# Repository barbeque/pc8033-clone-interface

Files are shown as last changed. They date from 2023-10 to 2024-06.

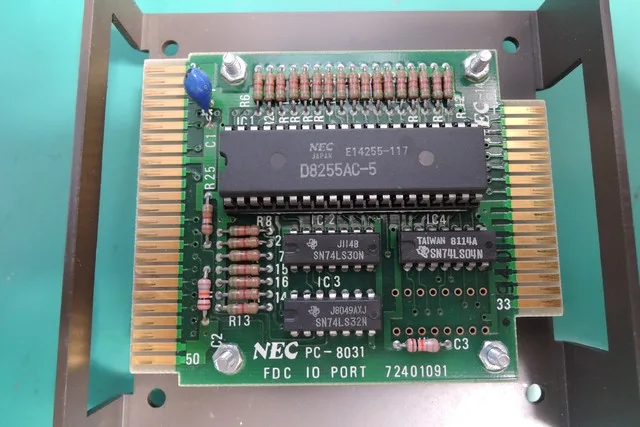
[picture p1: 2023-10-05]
References/real-pc-8033.webp

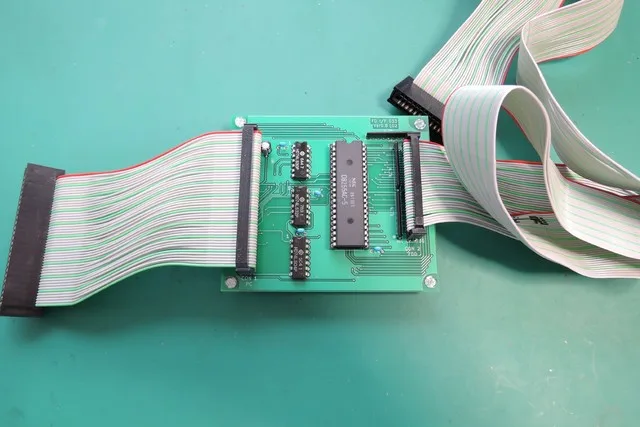
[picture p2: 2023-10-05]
References/diy 8033 2.webp

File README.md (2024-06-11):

# PC-8033 Clone Interface
This open-source hardware allows original-model NEC PC-8001 computers to use intelligent-type floppy drives such as the PC-8031-2W and PC-80S31.

## BOM
Please consult the [interactive bom](/bom/) for the most helpful view.

| Reference | Component | Digi-Key link | Comment |
|---|---|---|---|
| C1 | 220µF capacitor | | |
| C2 | 0.1µF capacitor | | |
| R1 | 4.7kΩ resistor | | |
| U1 | 2x25-pin (50-pin) pin header | | |
| U2 | DIP 74LS32 | | |
| U3 | DIP 74LS04 | | |
| U4 | DIP Intel (or clone) 8255 | | |
| U5 | DIP 74LS30 | | |
| RN1, RN2, RN3 | 4.7kΩ bussed 8-resistor network (9-pin) | | |
| J2 | 2x17 (PC-8031) or 2x18 (PC-80S31) pin header | | |

## Cable from PC-8001
A 50-pin female edge connector and 50-pin female 0.1" IDC header are required. Crimp a straight 50-pin ribbon cable, such that pin 1 of the edge connector connects to pin 1 of the female IDC header. Attach to PC-8033 clone board, paying attention to board callout for pin "01."

## Cable to Floppy Drive
A cable will have to be made to connect to the disk drive.

### PC-8031-2W (34-pin edge connector)
Use an IDC crimper to crimp a 34-pin ribbon into 34-pin female (0.1") and 34-pin edge connector. Do not cross over (pin 1 on J2 should be pin 1 on the floppy drive.)

Connect to floppy drive, paying attention to pin 1 arrow on back.

### PC-80S31 (36-pin 57-series Centronics)
Use an IDC crimper to crimp a 36-pin ribbon into a 36-pin female (0.1") and 36-pin Centronics connector. Do not cross over.

Connect to floppy drive.

## Enclosure
TBD

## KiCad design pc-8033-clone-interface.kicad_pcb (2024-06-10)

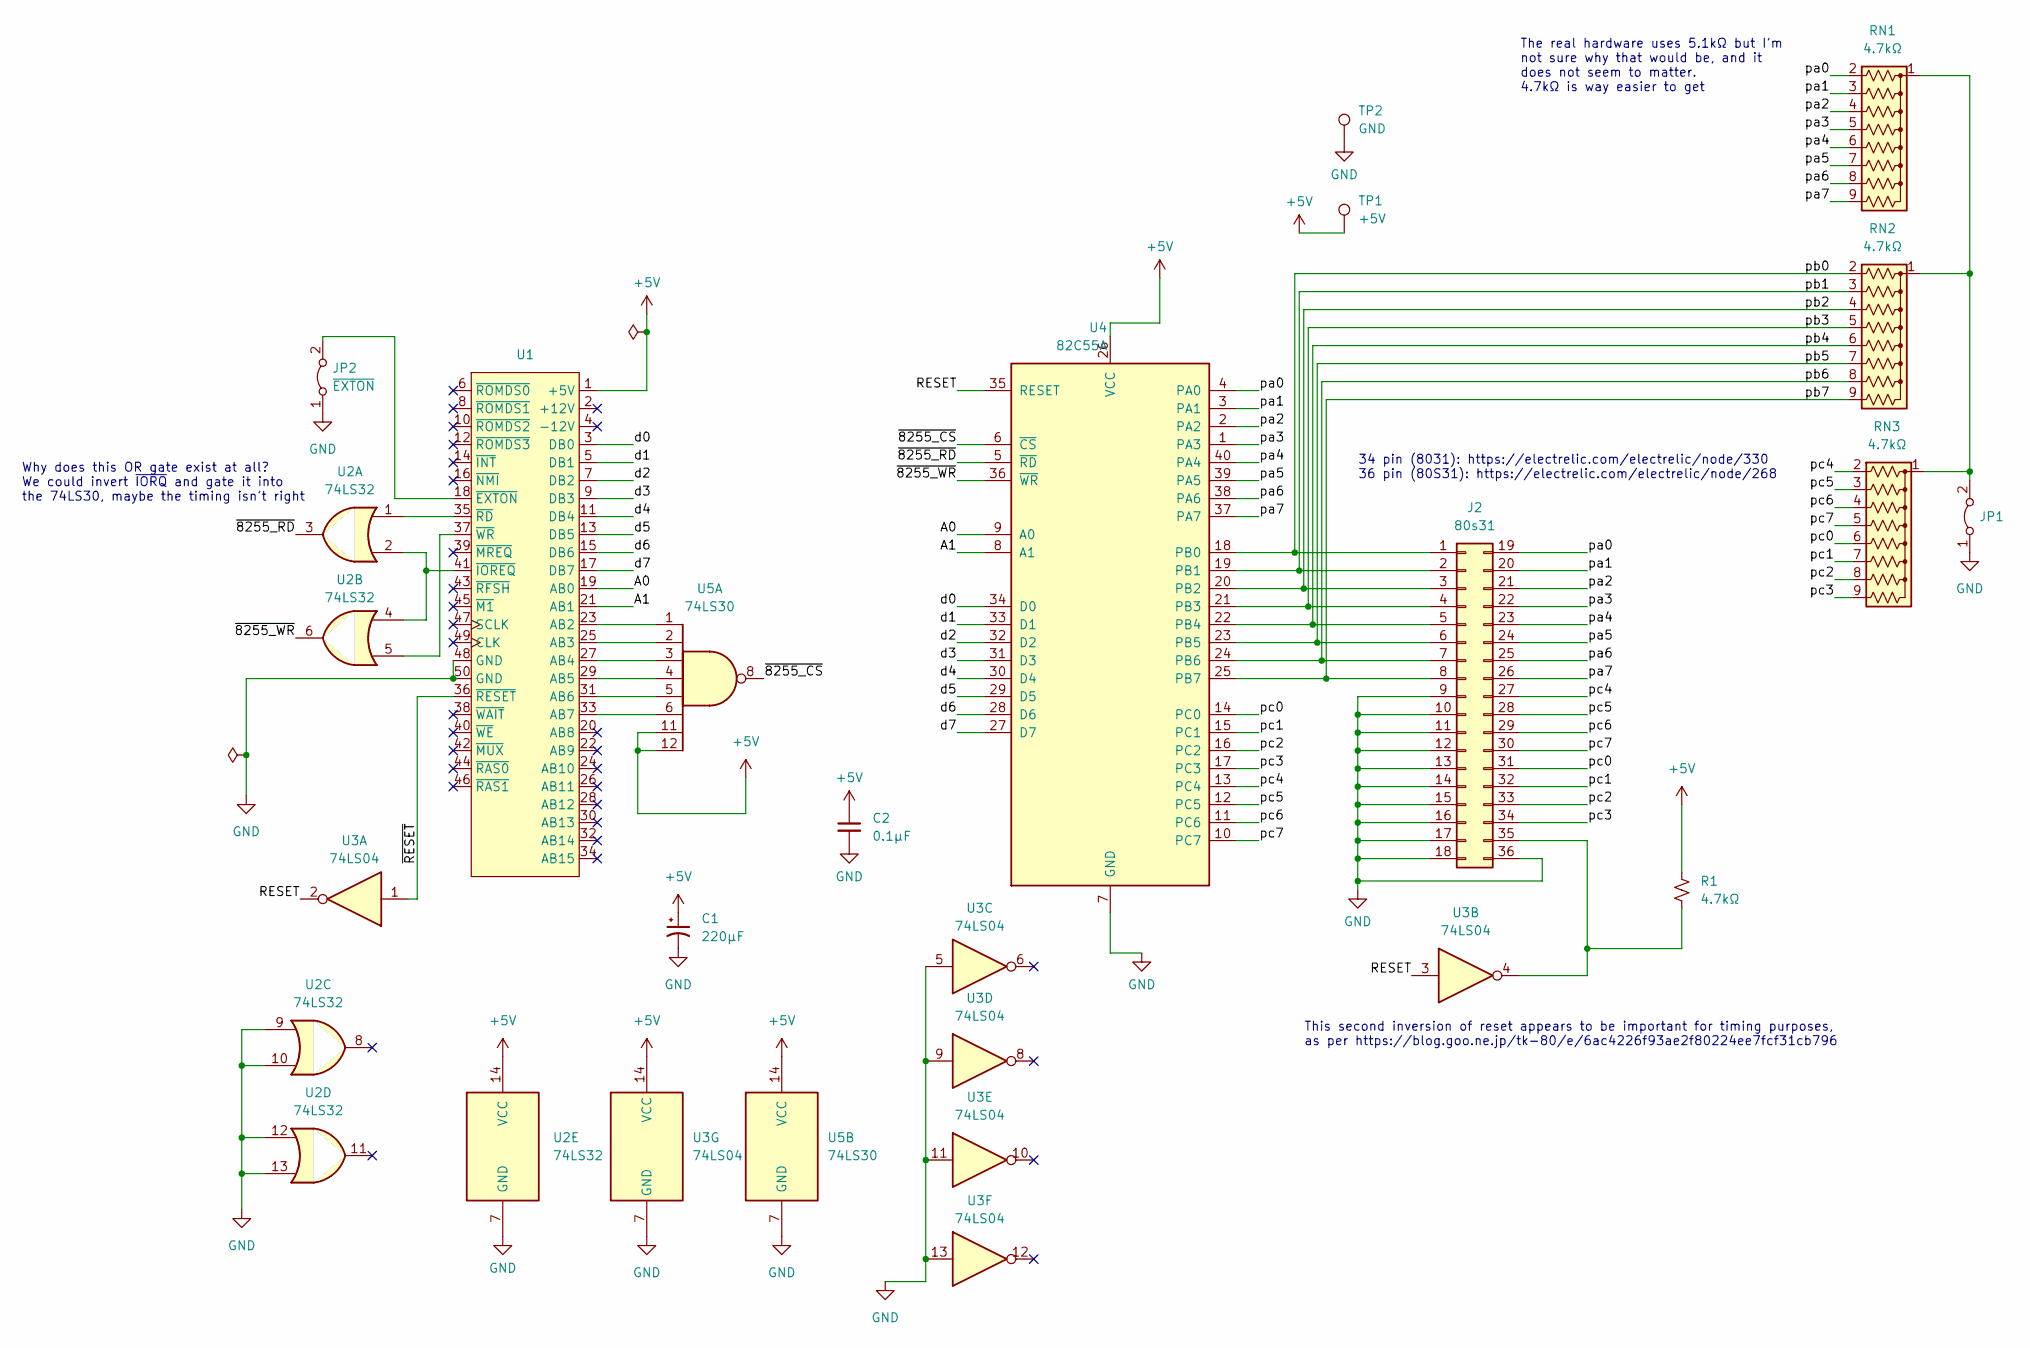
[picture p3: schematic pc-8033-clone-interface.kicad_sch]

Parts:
C1: 220µF; CP_Radial_D6.3mm_P2.50mm
C2: 0.1µF; C_Disc_D3.4mm_W2.1mm_P2.50mm
J2: 80s31; Centronics_36_FDD
JP1: Jumper_2_Bridged; SolderJumper-2_P1.3mm_Bridged2Bar_Pad1.0x1.5mm
JP2: ~{EXTON}; SolderJumper-2_P1.3mm_Bridged2Bar_Pad1.0x1.5mm
R1: 4.7kΩ; R_Axial_DIN0309_L9.0mm_D3.2mm_P12.70mm_Horizontal
RN1, RN2, RN3: 4.7kΩ; R_Array_SIP9
TP1: +5V; TestPoint_Loop_D1.80mm_Drill1.0mm_Beaded
TP2: GND; TestPoint_Loop_D1.80mm_Drill1.0mm_Beaded
U1: PinHeader_2x25_P2.54mm_Vertical
U2: 74LS32
U3: 74LS04
U4: 82C55A; DIP-40_W15.24mm
U5: 74LS30; DIP-14_W7.62mm_Socket_LongPads

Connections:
+5V: C1.1, C2.1, R1.1, TP1.1, U1.1 (+5V), U2.14 (VCC), U3.14 (VCC), U4.26 (VCC), U5.11, U5.12, U5.14 (VCC)
/A0: U1.19 (AB0), U4.9 (A0)
/A1: U1.21 (AB1), U4.8 (A1)
/RESET: U3.2, U3.3, U4.35 (RESET)
/d0: U1.3 (DB0), U4.34 (D0)
/d1: U1.5 (DB1), U4.33 (D1)
/d2: U1.7 (DB2), U4.32 (D2)
/d3: U1.9 (DB3), U4.31 (D3)
/d4: U1.11 (DB4), U4.30 (D4)
/d5: U1.13 (DB5), U4.29 (D5)
/d6: U1.15 (DB6), U4.28 (D6)
/d7: U1.17 (DB7), U4.27 (D7)
/pa0: J2.19, RN1.2 (R1), U4.4 (PA0)
/pa1: J2.20, RN1.3 (R2), U4.3 (PA1)
/pa2: J2.21, RN1.4 (R3), U4.2 (PA2)
/pa3: J2.22, RN1.5 (R4), U4.1 (PA3)
/pa4: J2.23, RN1.6 (R5), U4.40 (PA4)
/pa5: J2.24, RN1.7 (R6), U4.39 (PA5)
/pa6: J2.25, RN1.8 (R7), U4.38 (PA6)
/pa7: J2.26, RN1.9 (R8), U4.37 (PA7)
/pb0: J2.1, RN2.2 (R1), U4.18 (PB0)
/pb1: J2.2, RN2.3 (R2), U4.19 (PB1)
/pb2: J2.3, RN2.4 (R3), U4.20 (PB2)
/pb3: J2.4, RN2.5 (R4), U4.21 (PB3)
/pb4: J2.5, RN2.6 (R5), U4.22 (PB4)
/pb5: J2.6, RN2.7 (R6), U4.23 (PB5)
/pb6: J2.7, RN2.8 (R7), U4.24 (PB6)
/pb7: J2.8, RN2.9 (R8), U4.25 (PB7)
/pc0: J2.31, RN3.6 (R5), U4.14 (PC0)
/pc1: J2.32, RN3.7 (R6), U4.15 (PC1)
/pc2: J2.33, RN3.8 (R7), U4.16 (PC2)
/pc3: J2.34, RN3.9 (R8), U4.17 (PC3)
/pc4: J2.27, RN3.2 (R1), U4.13 (PC4)
/pc5: J2.28, RN3.3 (R2), U4.12 (PC5)
/pc6: J2.29, RN3.4 (R3), U4.11 (PC6)
/pc7: J2.30, RN3.5 (R4), U4.10 (PC7)
/~8255_CS: U4.6 (~CS), U5.8
/~8255_RD: U2.3, U4.5 (~RD)
/~8255_WR: U2.6, U4.36 (~WR)
/~RESET: U1.36 (~RESET), U3.1
GND: C1.2, C2.2, J2.9, J2.10, J2.11, J2.12, J2.13, J2.14, J2.15, J2.16, J2.17, J2.18, J2.36, JP1.1 (A), JP2.1 (A), TP2.1, U1.48 (GND), U1.50 (GND), U2.7 (GND), U2.9, U2.10, U2.12, U2.13, U3.5, U3.7 (GND), U3.9, U3.11, U3.13, U4.7 (GND), U5.7 (GND)
unnamed: J2.35, R1.2, U3.4
unnamed: JP1.2 (B), RN1.1 (common), RN2.1 (common), RN3.1 (common)
unnamed: JP2.2 (B), U1.18 (~EXTON)
unnamed: U1.23 (AB2), U5.1
unnamed: U1.25 (AB3), U5.2
unnamed: U1.27 (AB4), U5.3
unnamed: U1.29 (AB5), U5.4
unnamed: U1.31 (AB6), U5.5
unnamed: U1.33 (AB7), U5.6
unnamed: U1.41 (~IOREQ), U2.2, U2.4
unnamed: U1.35 (~RD), U2.1
unnamed: U1.37 (~WR), U2.5

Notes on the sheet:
The real hardware uses 5.1kΩ but I'm not sure why that would be, and it does not seem to matter. 4.7kΩ is way easier to get
This second inversion of reset appears to be important for timing purposes, as per https://blog.goo.ne.jp/tk-80/e/6ac4226f93ae2f80224ee7fcf31cb796
Why does this OR gate exist at all? We could invert ~{IORQ} and gate it into the 74LS30, maybe the timing isn't right
34 pin (8031): https://electrelic.com/electrelic/node/330 36 pin (80S31): https://electrelic.com/electrelic/node/268

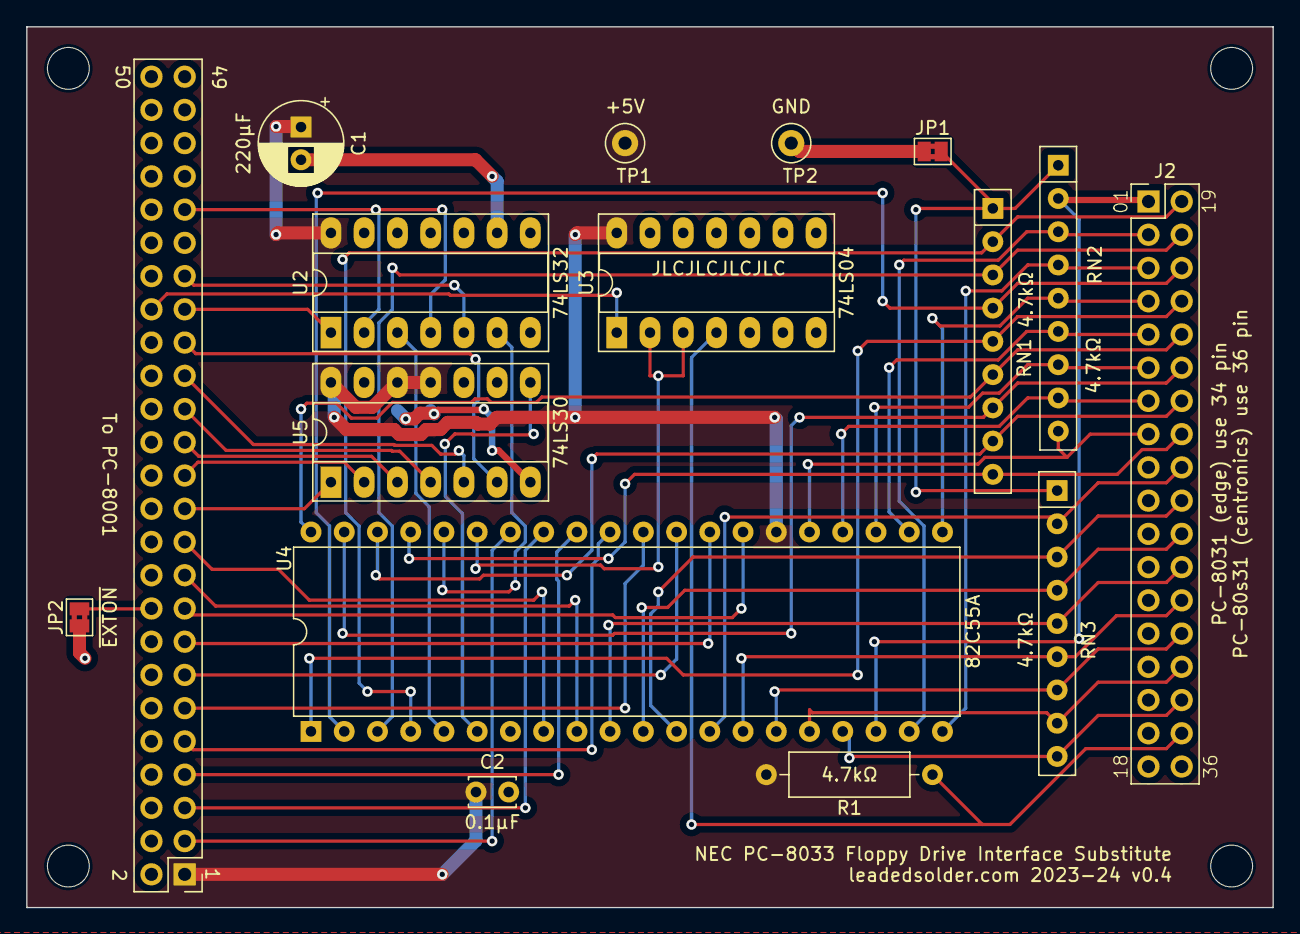
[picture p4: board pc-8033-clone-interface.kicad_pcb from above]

Board: 2 copper layers, 95.2 x 67.3 mm, 16 parts (0 on the bottom side), 53 nets.

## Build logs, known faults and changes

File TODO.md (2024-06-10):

 - [ ] Design a case using turbocase
 - [ ] Get some build instructions together
 - [ ] Consider alternative ways to offer a 34/36 dual footprint without bending pins
 - [ ] Clean up TODOs

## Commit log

2023-10-05 Initial wire up from 8001 to 8255
    [pc-8033-clone-interface.kicad_pcb, pc-8033-clone-interface.kicad_sch]
2023-10-05 Still trying to puzzle out the interface here
    [pc-8033-clone-interface.kicad_sch]
2023-10-05 Now we're getting into the troubles
    [pc-8033-clone-interface.kicad_sch]
2023-10-05 Reset faffing
    [pc-8033-clone-interface.kicad_sch]
2023-10-05 EXTON strapped low
    [pc-8033-clone-interface.kicad_sch]
2023-10-06 Capture dual footprint IDC header
    [pc-8033-clone-interface.kicad_sch]
2023-10-06 Clean up stale TODO
    [pc-8033-clone-interface.kicad_sch]
2023-10-06 Clean up schem warnings
    [pc-8033-clone-interface.kicad_sch]
2023-10-06 Lots of clearance issues...
    [pc-8033-clone-interface.kicad_pcb, pc-8033-clone-interface.kicad_sch]
2023-10-06 Tear drops
    [pc-8033-clone-interface.kicad_pcb]
2023-11-27 V1 released to fab
    [pc-8033-clone-interface.kicad_pcb]
2023-12-29 Rotate 50-pin connector
    [pc-8033-clone-interface.kicad_pcb]
2024-02-19 Short the EXTON pin instead of trying to gently pull it down
    [pc-8033-clone-interface.kicad_pcb, pc-8033-clone-interface.kicad_sch]
2024-02-19 add a smaller decoupling cap on the 8255
    [pc-8033-clone-interface.kicad_pcb, pc-8033-clone-interface.kicad_sch]
2024-02-19 Use weird Centronics pinout on board
    [pc-8033-clone-interface.kicad_pcb, pc-8033-clone-interface.kicad_sch]
2024-02-19 V2 sent to JLCPCB
    [pc-8033-clone-interface.kicad_pcb]
2024-03-01 V3: fix the pinout once and for all
    [pc-8033-clone-interface.kicad_pcb, pc-8033-clone-interface.kicad_sch]
2024-03-17 Fix select logic
    [pc-8033-clone-interface.kicad_pcb, pc-8033-clone-interface.kicad_sch]
2024-03-25 Add header pin numbers to the underside for kicks
    [pc-8033-clone-interface.kicad_pcb]
2024-03-26 Move a pullup to look nicer
    [pc-8033-clone-interface.kicad_sch]
2024-06-10 Some self-doubt comments
    [pc-8033-clone-interface.kicad_pcb, pc-8033-clone-interface.kicad_sch]
